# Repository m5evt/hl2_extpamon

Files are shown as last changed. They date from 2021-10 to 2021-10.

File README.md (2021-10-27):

# hl2_extpamon

## Overview

hl2_extpamon

Power amplifier instrumentation board designed to couple to the Hermes-Lite2 SDR. 

The firmware/hardware is designed to couple to an LM35 temperature sensor.

The hardware should cope with upto 8 A of current to a power amplifer. However, at present the current is scaled to a full scale of 5 A. This can be changed in [hl2_extpamon.h](https://github.com/m5evt/hl2_extpamon/blob/main/firmware/hl2_extpamon.h). Other parameters such as automatic temperature turn on for the fan can be configured here.

The module uses an ATTINY414 device with an i2c address of 0x2A. 

## Reading data from device

Data can be read from the device over i2c by send the first data frame as 0x01.

For example, to read temperature and current from the device send:

```
07AA0100
```

This will return a 16 bit number comprised of the following bytes:

| Byte 3  | Byte 2 | Byte 1  | Byte 0 |
| --- | --- |--- | --- |
| Device status | PORTA status |Current | Temperature |

Temperature = e.g. 26 is 26 deg C

Current is scaled to a maximum current of 5 A represented in 255 bits. A return value of 128 = (128 / 255) * 5 = 2.51 A.

PORTA status corresponds to:

| Bit | Description |
|--- | --- |
| 0 | Reserved |
| 1 | HL2 CN8 control |
| 2 | Enable PA power |
| 3 | FAN 1 |
| 4 | FAN 2 |
| 5 | N/a
| 6 | N/a
| 7 | Reserved |

Device status correspod to:

| Bit | Description |
|--- | --- |
| 0 | Sampling ADC5 |
| 1 | Sampling ADC6 |

## Writing data to device

PORTA I/O can be set/clear by writing to address 0x02 in the device. For example, to enable the PA and turn on the fans send:

```
06AA021E
```

## Programming the ATTINY414

To program, the Makefile uses [pymcuprog](https://github.com/microchip-pic-avr-tools/pymcuprog) and UPDI. This does not require any specialist tools other than a TTL USB adapter and a resistor. See [here](https://github.com/mraardvark/pyupdi).

To program the device, from a command line run:
```
make clean && make erase && make program
```

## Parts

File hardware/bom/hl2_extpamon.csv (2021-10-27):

ID | Value |  | Quantiy | Vendor | Order code
C1, C2, C3, C4, C5, C6, C7, C8, C60, C81, C84, C85 | 100n | C_0603_1608Metric_Pad1.08x0.95mm_HandSolder | 12
C83 | 1u | C_0603_1608Metric_Pad1.08x0.95mm_HandSolder | 1
R1, R2 | 10k | R_0603_1608Metric_Pad0.98x0.95mm_HandSolder | 2 | Farnell | 2887144
R4, R5, R6, R7, R8, R16 | 10k | R_0603_1608Metric_Pad0.98x0.95mm_HandSolder | 6
R3, R17 | 1k | R_0603_1608Metric_Pad0.98x0.95mm_HandSolder | 2
R14, R35 | 100 | R_0603_1608Metric_Pad0.98x0.95mm_HandSolder | 2
R31 | 100k | R_0603_1608Metric_Pad0.98x0.95mm_HandSolder | 1
R34 | 0.033 | rsense_1206wide | 1 | Farnell | 3254952
D2, D6 | 1N4148W | D_SOD-123 | 2 | Farnell | 1776392
D1 | BZT52C15-E3-08 | D_SOD-123 | 1 | Farnell | 2420637
U1 | MCP6282E/MS | MSOP-8_3x3mm_P0.65mm | 1 | Farnell | 1852089
U2 | ATtiny414-SS | SOIC-14_3.9x8.7mm_P1.27mm | 1 | Farnell | 2786358
U7 | INA193 | SOT-23-5 | 1 | Farnell | 3005325
FB6 | FB | L_0805_2012Metric | 1 | Farnell | 1800367
Q3, Q6 | IRLML6402 | SOT-23 | 2 | Farnell | 9103503
Q4, Q5 | DTC144E | SOT-23 | 2 | Farnell | 2948628
Q2 | 2N7002 | SOT-23 | 1 | Farnell | 9845313
Q1 | RSJ151P10TL | TO-263-3_TabPin2 | 1 | Farnell | 2706667
J5, J8 | Fan | JST_XH_B2B-XH-A_1x02_P2.50mm_Vertical | 2
J9 | Conn_01x04 | PinHeader_1x05_P2.54mm_Vertical | 1
J7 | Conn_01x08 | PinHeader_1x08_P2.54mm_Vertical | 1
J1, J3, J4 | 12V | TerminalBlock_Phoenix_PT-1,5-2-3.5-H_1x02_P3.50mm_Horizontal | 3 | Farnell | 1841250
J2, J6 | 50VDC | TerminalBlock_Phoenix_PT-1,5-2-5.0-H_1x02_P5.00mm_Horizontal | 2 | Farnell | 1733570
P1, P2, P3, P4 | TST | m3 | 4

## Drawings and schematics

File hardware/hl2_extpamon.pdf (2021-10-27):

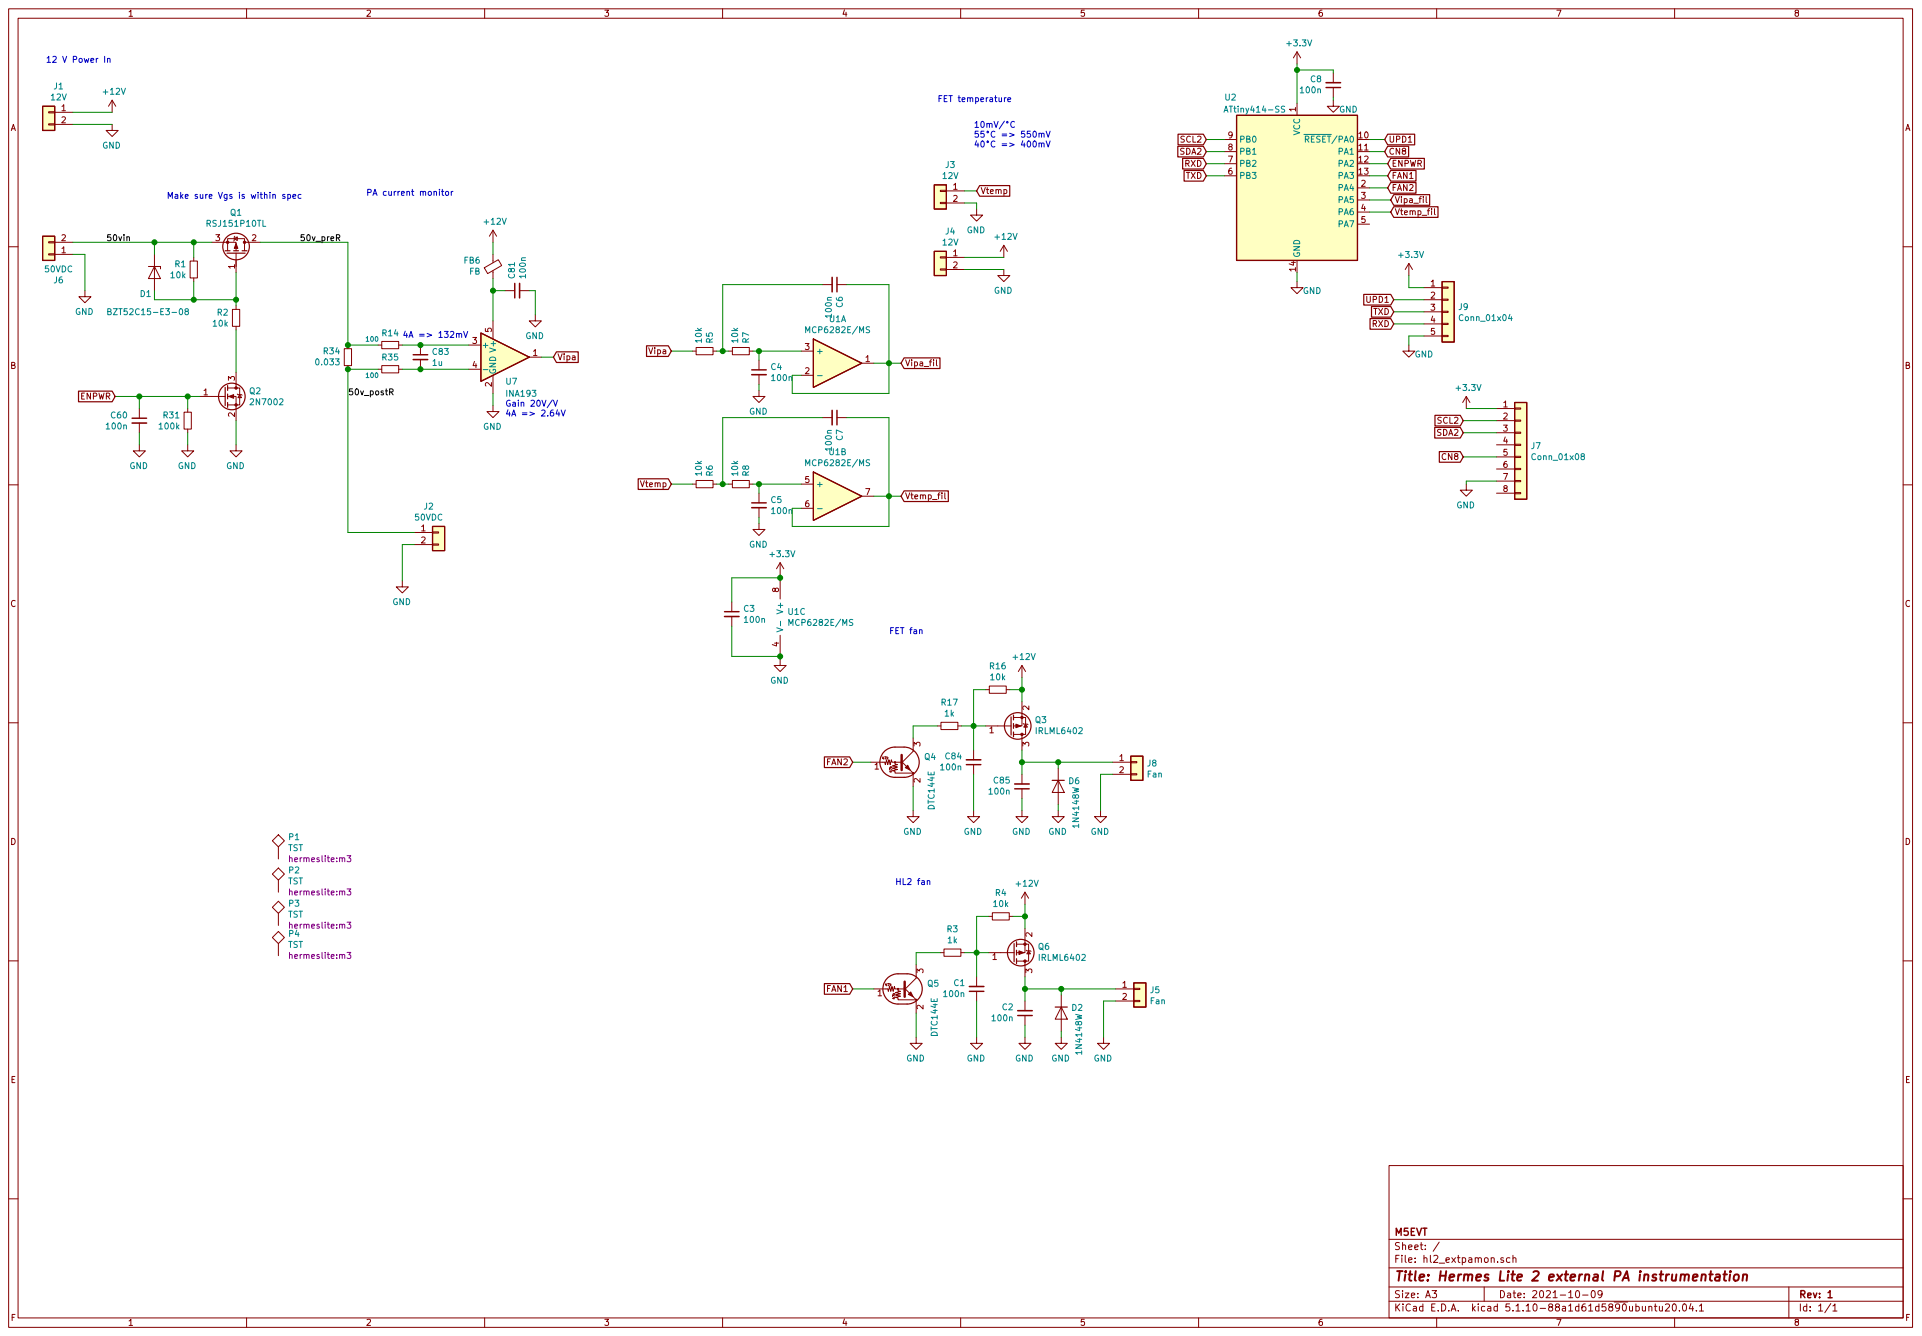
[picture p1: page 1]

FET temperature PA current monitor 4A => 132mV

Make sure Vgs is within spec

File: hl2_extpamon.sch Sheet: / M5EVT GND

Id: 1/1 Title: Hermes Lite 2 external PA instrumentation

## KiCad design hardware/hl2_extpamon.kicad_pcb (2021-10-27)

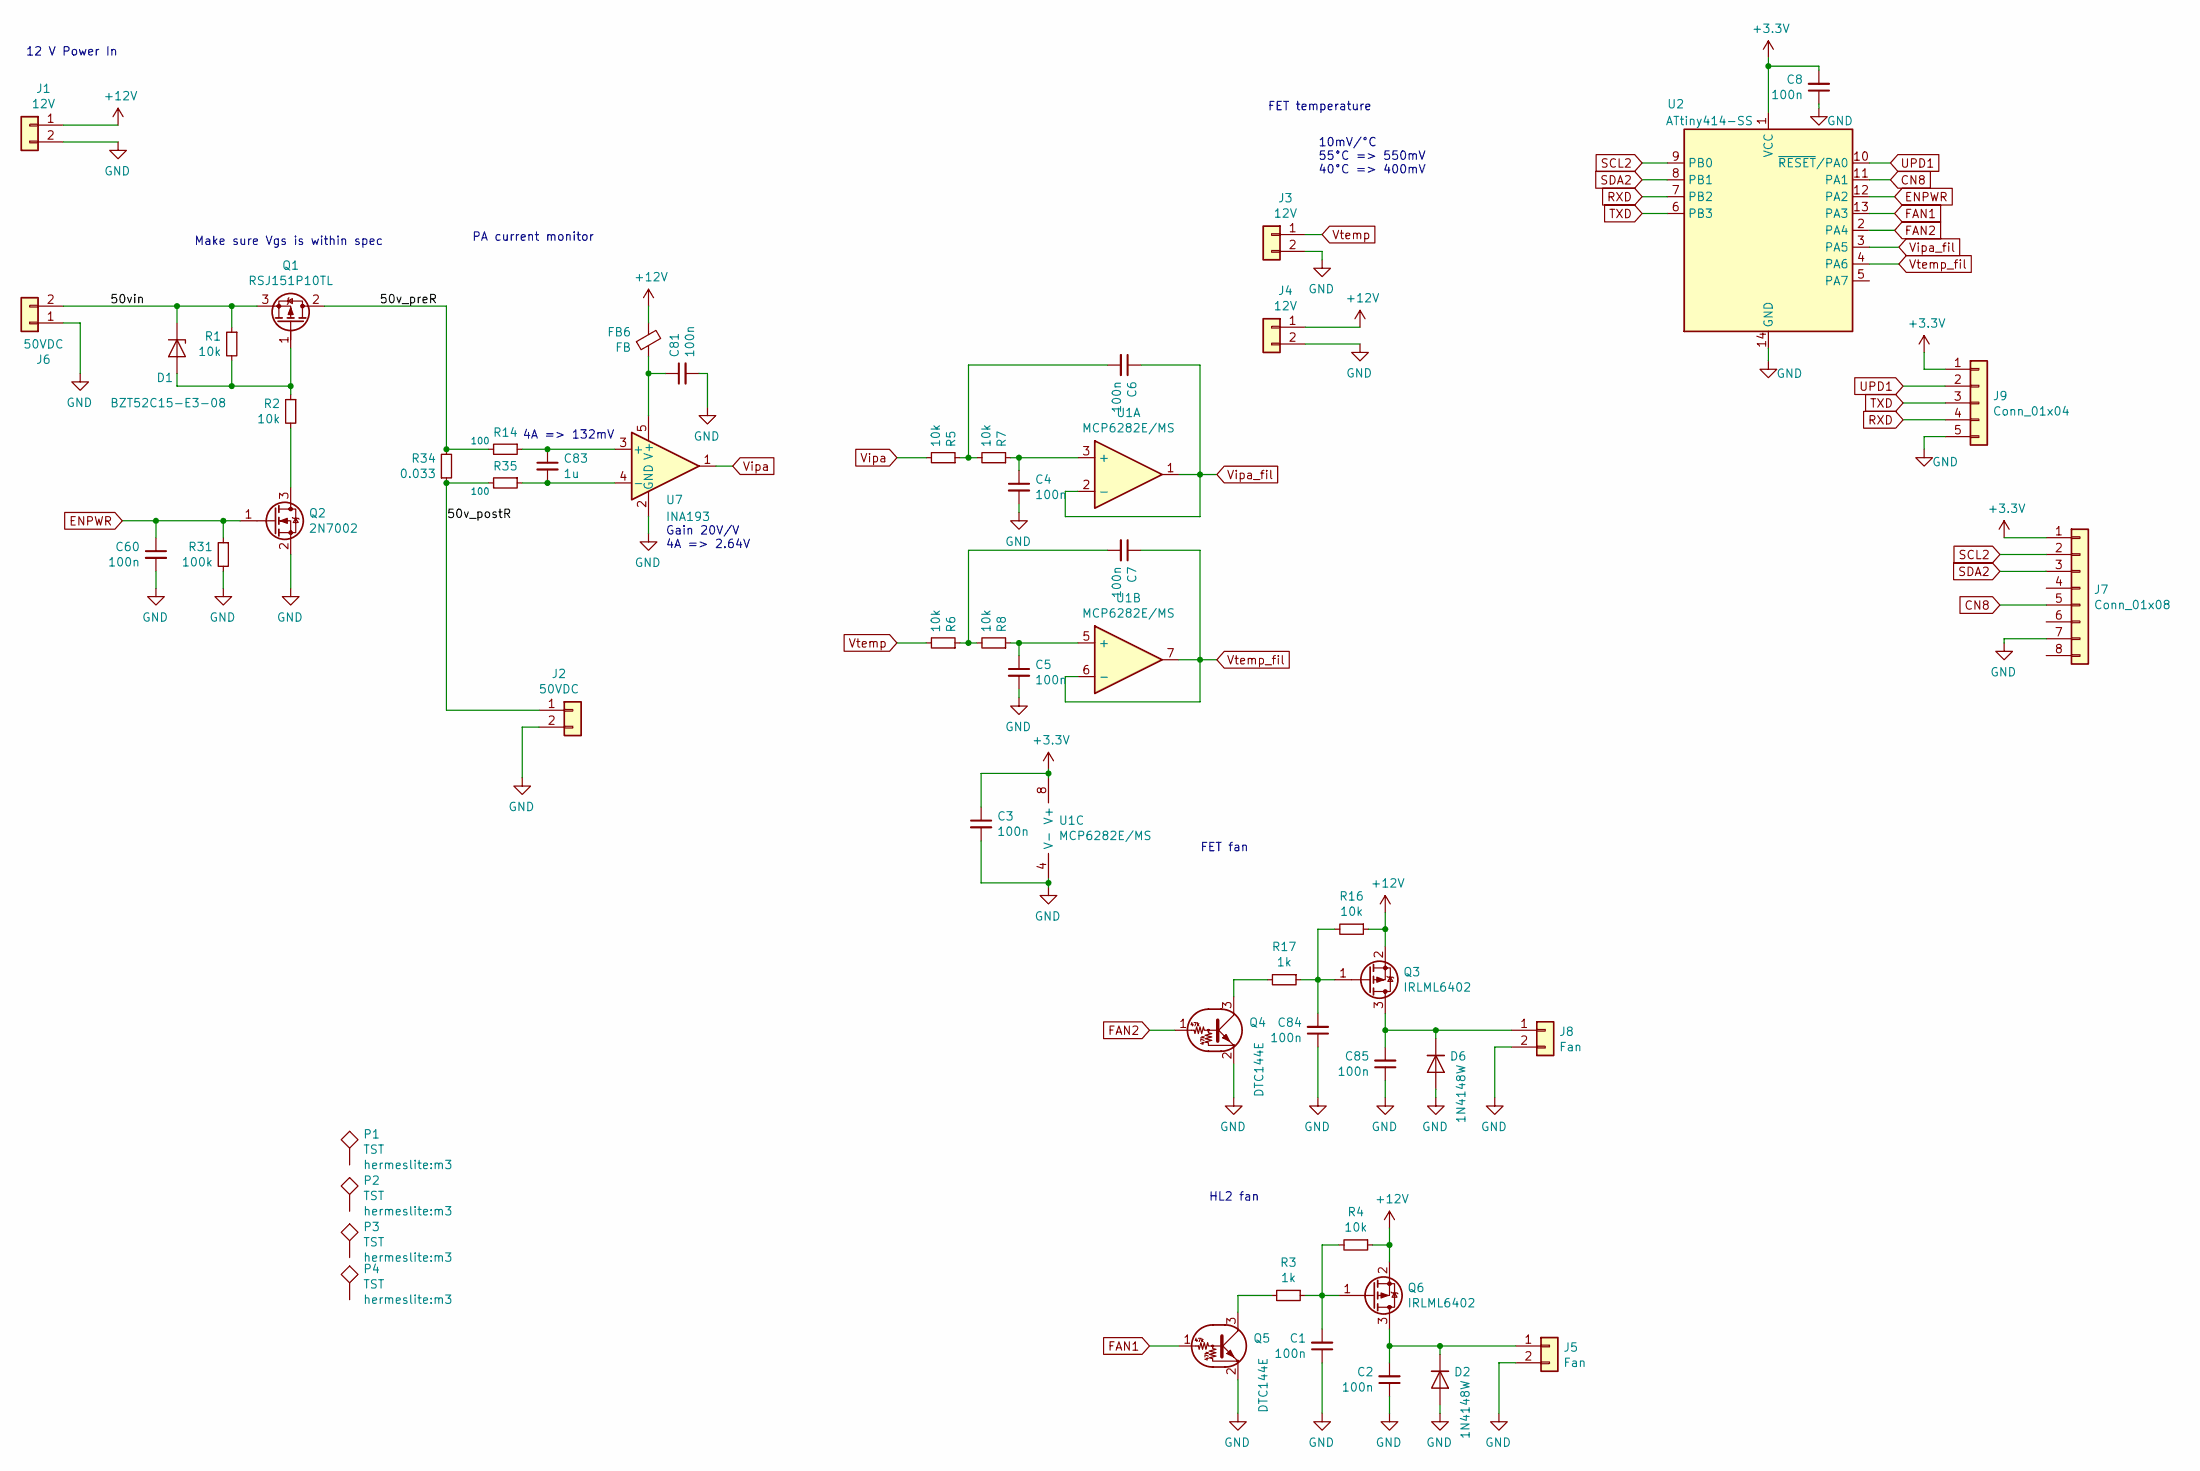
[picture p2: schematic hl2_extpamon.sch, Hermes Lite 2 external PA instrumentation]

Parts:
C1, C2, C3, C4, C5, C6, C7, C8, C60, C81, C84, C85: 100n; C_0603_1608Metric_Pad1.08x0.95mm_HandSolder
C83: 1u; C_0603_1608Metric_Pad1.08x0.95mm_HandSolder
D1: BZT52C15-E3-08; D_SOD-123
D2, D6: 1N4148W; D_SOD-123
FB6: FB; L_0805_2012Metric
J1, J3, J4: 12V; TerminalBlock_Phoenix_PT-1,5-2-3.5-H_1x02_P3.50mm_Horizontal
J2, J6: 50VDC; TerminalBlock_Phoenix_PT-1,5-2-5.0-H_1x02_P5.00mm_Horizontal
J5, J8: Fan; JST_XH_B2B-XH-A_1x02_P2.50mm_Vertical
J7: Conn_01x08; PinHeader_1x08_P2.54mm_Vertical
J9: Conn_01x04; PinHeader_1x05_P2.54mm_Vertical
P1, P2, P3, P4: TST; m3
Q1: RSJ151P10TL; TO-263-3_TabPin2
Q2: 2N7002; SOT-23
Q3, Q6: IRLML6402; SOT-23
Q4, Q5: DTC144E; SOT-23
R1, R2, R4, R5, R6, R7, R8, R16: 10k; R_0603_1608Metric_Pad0.98x0.95mm_HandSolder
R3, R17: 1k; R_0603_1608Metric_Pad0.98x0.95mm_HandSolder
R14, R35: 100; R_0603_1608Metric_Pad0.98x0.95mm_HandSolder
R31: 100k; R_0603_1608Metric_Pad0.98x0.95mm_HandSolder
R34: 0.033; rsense_1206wide
U1: MCP6282E/MS; MSOP-8_3x3mm_P0.65mm
U2: ATtiny414-SS; SOIC-14_3.9x8.7mm_P1.27mm
U7: INA193; SOT-23-5

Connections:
+3V3: C3.1, C8.2, J7.1, J9.1, U1.8 (V+), U2.1 (VCC)
+12V: FB6.2, J1.1, J4.1, Q3.2 (S), Q6.2 (S), R4.1, R16.1
/50v_postR: J2.1, R34.1, R35.2
/50v_preR: Q1.2 (D), R14.2, R34.2
/50vin: D1.1 (K), J6.2, Q1.3 (S), R1.1
CN8: J7.5, U2.11 (PA1)
ENPWR: C60.1, Q2.1 (G), R31.1, U2.12 (PA2)
FAN1: Q5.1 (B), U2.13 (PA3)
FAN2: Q4.1 (B), U2.2 (PA4)
GND: C1.1, C2.1, C3.2, C4.2, C5.2, C8.1, C60.2, C81.2, C84.1, C85.1, D2.2 (A), D6.2 (A), J1.2, J2.2, J3.2, J4.2, J5.2, J6.1, J7.7, J8.2, J9.5, Q2.2 (S), Q4.2 (E), Q5.2 (E), R31.2, U1.4 (V-), U2.14 (GND), U7.2 (GND)
unnamed: C1.2, Q6.1 (G), R3.1, R4.2
unnamed: C2.2, D2.1 (K), J5.1, Q6.3 (D)
unnamed: C4.1, R7.1, U1.3 (+)
unnamed: C5.1, R8.1, U1.5 (+)
unnamed: C6.2, R5.1, R7.2
unnamed: C7.2, R6.1, R8.2
unnamed: C81.1, FB6.1, U7.5 (V+)
unnamed: C83.1, R14.1, U7.3 (+)
unnamed: C83.2, R35.1, U7.4 (-)
unnamed: C84.2, Q3.1 (G), R16.2, R17.1
unnamed: C85.2, D6.1 (K), J8.1, Q3.3 (D)
unnamed: D1.2 (A), Q1.1 (G), R1.2, R2.1
unnamed: Q2.3 (D), R2.2
unnamed: Q4.3 (C), R17.2
unnamed: Q5.3 (C), R3.2
RXD: J9.4, U2.7 (PB2)
SCL2: J7.2, U2.9 (PB0)
SDA2: J7.3, U2.8 (PB1)
TXD: J9.3, U2.6 (PB3)
UPD1: J9.2, U2.10 (~RESET~/PA0)
Vipa: R5.2, U7.1
Vipa_fil: C6.1, U1.1, U1.2 (-), U2.3 (PA5)
Vtemp: J3.1, R6.2
Vtemp_fil: C7.1, U1.6 (-), U1.7, U2.4 (PA6)

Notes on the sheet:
10mV/°C 55°C => 550mV 40°C => 400mV
4A => 132mV
Gain 20V/V 4A => 2.64V
PA current monitor
FET temperature
FET fan
HL2 fan
Make sure Vgs is within spec
12 V Power In

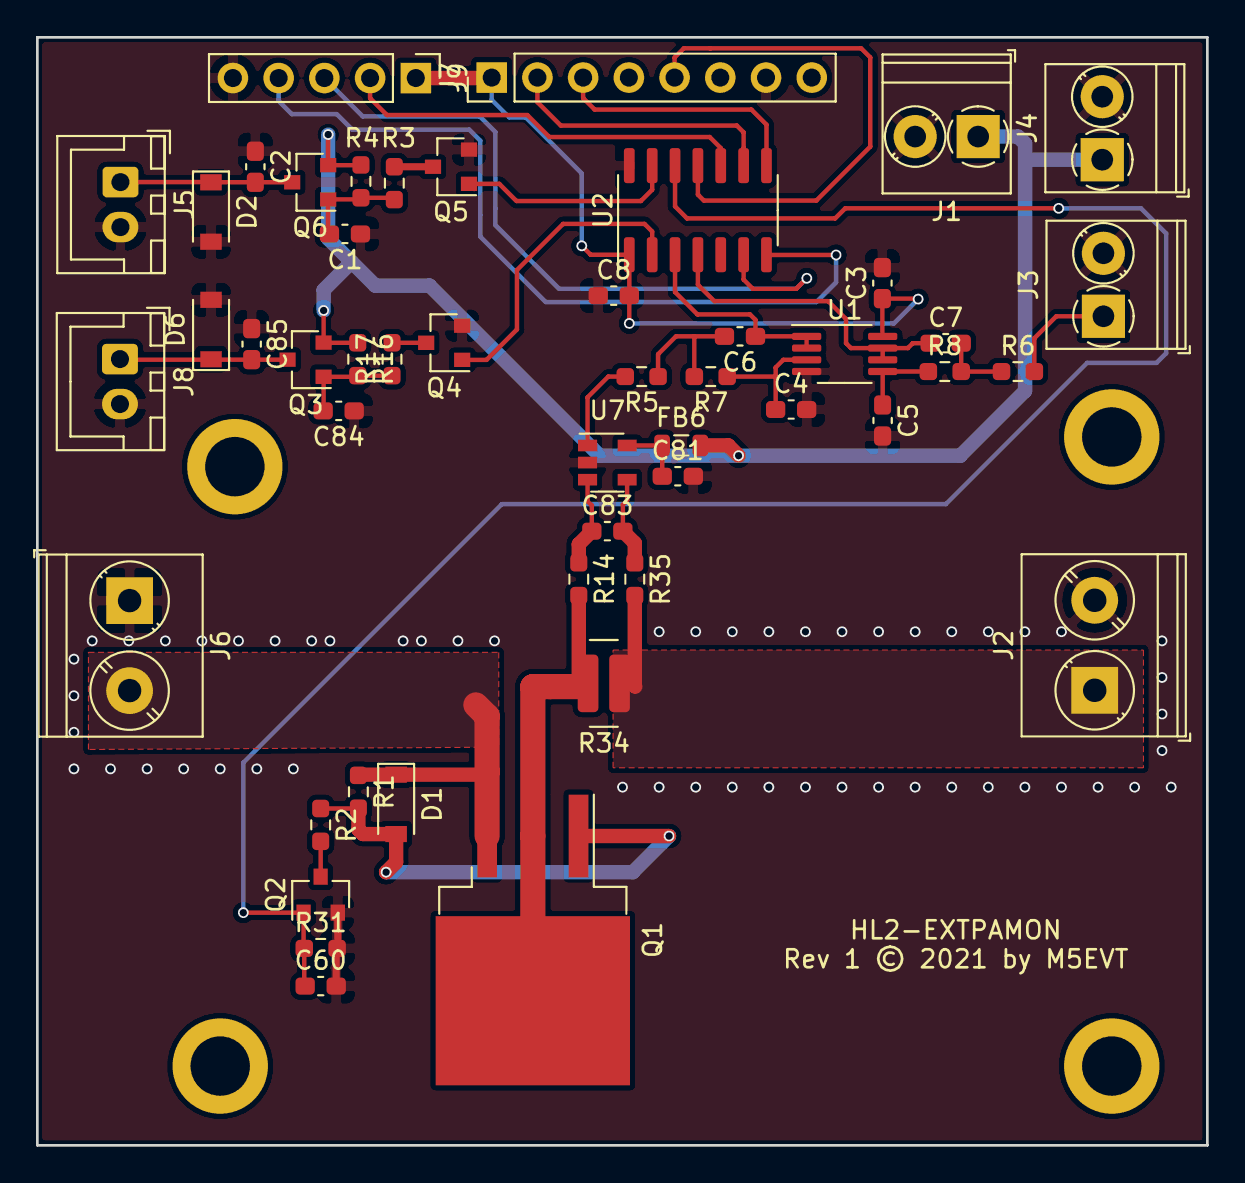
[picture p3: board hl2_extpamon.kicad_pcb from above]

Board: 2 copper layers, 65.0 x 61.6 mm, 53 parts (0 on the bottom side), 34 nets.

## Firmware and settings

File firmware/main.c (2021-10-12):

/*
 *
 * This software is covered by a modified MIT License, see paragraphs 4
 *
 * Copyright (c) 2021 m5evt 
 *
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
 * 4. Parts of this software are adapted from Microchip sample code.
 * Additional license restrictions from Microchip may apply.
 */

#define TEN_MS_PERIOD (0x1388)

#include <avr/io.h>
#include <avr/interrupt.h>

#include "helper.h"
#include "I2CS.h"
#include "hl2_extpamon.h"

// Globals
volatile uint8_t temperature_raw;
volatile uint8_t current_raw;
volatile uint8_t status_reg;
volatile uint8_t fan_counter;
volatile uint8_t trip_current;
volatile uint8_t trip_temperature;


void TCA0_init(void) {
    // enable overflow interrupt 
    TCA0.SINGLE.INTCTRL = TCA_SINGLE_OVF_bm;
    // set Normal mode 
    TCA0.SINGLE.CTRLB = TCA_SINGLE_WGMODE_NORMAL_gc;
    // disable event counting 
    TCA0.SINGLE.EVCTRL &= ~(TCA_SINGLE_CNTEI_bm);
    // set the period 
    TCA0.SINGLE.PER = TEN_MS_PERIOD;
    TCA0.SINGLE.CTRLA = TCA_SINGLE_CLKSEL_DIV16_gc | TCA_SINGLE_ENABLE_bm;
}

void RTC_init(void) {
  //Wait for all register to be synchronized 
  while (RTC.STATUS > 0) {};
  
  RTC.CTRLA = RTC_PRESCALER_DIV1_gc   // 1 
            | 1 << RTC_RTCEN_bp     // Enable: enabled 
            | 0 << RTC_RUNSTDBY_bp; // Run In Standby: disabled
  // Wait for all register to be synchronized 
  while (RTC.PITSTATUS > 0) {} 
  RTC.PITCTRLA = RTC_PERIOD_CYC32_gc  // RTC Clock  Cycles 32 
               | 1 << RTC_PITEN_bp; // Enable: enabled 
 
  RTC.PITINTCTRL = 1 << RTC_PI_bp; //Periodic Interrupt: enabled 
}

void PORT_init(void) {
  // set pin 0 of PORT A as output
  PORTA.DIR |= PIN4_bm;
  PORTA.DIR |= PIN3_bm;
  PORTA.DIR |= PIN1_bm;
  PORTA.DIR |= PIN2_bm;
}

void ADC0_init(void) {
  // Disable digital input buffer
  PORTA.PIN6CTRL &= ~PORT_ISC_gm;
  PORTA.PIN6CTRL |= PORT_ISC_INPUT_DISABLE_gc;
  PORTA.PIN5CTRL &= ~PORT_ISC_gm;
  PORTA.PIN5CTRL |= PORT_ISC_INPUT_DISABLE_gc;

  // Disable pull-up resistor 
  PORTA.PIN6CTRL &= ~PORT_PULLUPEN_bm;
  PORTA.PIN5CTRL &= ~PORT_PULLUPEN_bm;

  ADC0.CTRLC = ADC_PRESC_DIV4_gc
             | ADC_REFSEL_VDDREF_gc;
  ADC0.CTRLA = ADC_ENABLE_bm
             | ADC_RESSEL_10BIT_gc;
}

uint16_t ADC0_read(const uint8_t muxpos) {
  // Select analog input
  ADC0.MUXPOS = (muxpos<<0); 
   //Start conversion
  ADC0.COMMAND = ADC_STCONV_bm;
  // Wait til done
  while (!(ADC0.INTFLAGS & ADC_RESRDY_bm)) {;}
  //Done, clear INT
  ADC0.INTFLAGS = ADC_RESRDY_bm;
  // 12 bit result
  return ADC0.RES;
}

// Send data to the HL2
uint8_t i2cGetData(const uint8_t read_addr, const uint8_t this_byte){
  switch (read_addr) {
    case FLAGS_STATUS:
      return IOPORT;
      break;
    case MRF101_STATUS:
      switch (this_byte) {
        case 0:
          return temperature_raw;
        case 1:
          return current_raw;
        case 2:
          return IOPORT;
        case 3:
          return status_reg;
        default: break;
      break;
    }
  }
  return 0x1f;
}

// Read byte sent from HL2
uint8_t i2cWriteData(const uint8_t write_addr, const uint8_t data) {
  switch (write_addr) {
    case SET_CFG:
      IOPORT = data;
      break;
    case SET_CURRENT_TRIP:
      trip_current = data;
      break;
    case SET_TEMP_TRIP:
      trip_temperature = data;
      break;
    default: break;
  }
  return IOPORT;
}

void SetupProtectedWrites(void) {
    _PROTECTED_WRITE(CLKCTRL.MCLKCTRLB, CLKCTRL_PDIV_2X_gc | CLKCTRL_PEN_bm);
    _PROTECTED_WRITE(CLKCTRL.MCLKCTRLA, !CLKCTRL_CLKOUT_bm | CLKCTRL_CLKSEL_OSC20M_gc);
    _PROTECTED_WRITE(CLKCTRL.OSC32KCTRLA, CLKCTRL_RUNSTDBY_bp);
}

void InitUc(void) {
    SetupProtectedWrites();
    PORT_init();
    TCA0_init();
    RTC_init();
    ADC0_init();
    I2CS_init();
}

void InitStatusFlags(void) {
    // Fans off, ADC mux 0, CN8 disabled, PWR disabled 
    IOPORT = 0x00;
}

void GetTemperature(void) {
  uint16_t temp_raw = ADC0_read(TEMPERATURE);
  float this_temperature = ((float)temp_raw * (3.3 / 1024)) * 100;
            
  //temperature_raw = (uint8_t)(((float)temp_raw * (3.3 / 1024)) * 100);
  temperature_raw = (uint8_t)this_temperature;
  // Every 4080 ms sample the temperature to decide
  // if; fan turns on, fan stays off, fan turns off (after being on)
  if (fan_counter == 0) {
    if (temperature_raw > FAN_TEMP_THRESHOLD) {
      FAN1 = 1;
    }
    else {
      FAN1 = 0;
    }
    fan_counter++;
  } 
  else if (fan_counter == 255) {
    fan_counter = 0;
  }
  else if (fan_counter > 0) {
    fan_counter++;
  }
  if (temperature_raw > trip_temperature) {
    ENPWR = 0;
  }
  CBI(status_reg, 0);      
}

void GetCurrent(void) {
  uint16_t temp = ADC0_read(CURRENT);
  // Convert ADC bits to real value e.g. 4.00 A 
  float this_c = ((float)temp * (3.3 /1024) / 20) / CURRENT_SENSE_R;
  // To fit into an 8 bit reg, measured value to full scale
  current_raw = (uint8_t)((this_c / CURRENT_FULL_SCALE) * 255);
  if (current_raw > trip_current) {
    ENPWR = 0;
  }
  SBI(status_reg, 0);      
}

int main(void) {
    // Setup micro specifics 
    InitUc();
    // I2C callbacks to application code
    I2c_set_callbacks(i2cGetData, i2cWriteData);
    // Setup application code
    InitStatusFlags();
   
    // Init globals
    temperature_raw = 0;
    current_raw = 0;
    status_reg = 0;
    fan_counter = 0;
    trip_current = 178;
    trip_temperature = 45;

    // enable global interrupts */
    sei();
    
    temperature_raw = ADC0_read(TEMPERATURE);

    for (;;) {
       if ((status_reg & DO_ADC_M) == DO_ADC_M) {
     //PORTA.OUTTGL = PIN1_bm;
         if ((status_reg & ADCSAMPLE_M) == ADCSAMPLE_M) {
           GetTemperature();
         } 
         else {
           PORTA.OUTSET = PIN1_bm;
           GetCurrent();
           PORTA.OUTCLR = PIN1_bm;
         }
         CBI(status_reg, 1);
       }
    }
}

// ADC sampling timer (8 ms tick)
ISR(TCA0_OVF_vect) {
    // Set ADC sample flag
    SBI(status_reg, 1);
    // Clear flag 
    TCA0.SINGLE.INTFLAGS = TCA_SINGLE_OVF_bm;
}

// 1 ms tick 
ISR(RTC_PIT_vect) {					
    I2c_timeout_counter_inc();
    // Clear flag
  	RTC.PITINTFLAGS = RTC_PI_bm;		
}

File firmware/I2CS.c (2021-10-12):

/*
 * I2CS.c
 *
 * I2C client
 * 
 * This software is covered by a modified MIT License, see paragraphs 4 and 5
 *
 * Copyright (c) 2019 Dieter Reinhardt
 * Copyright (c) 2021 m5evt
 *
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
 * 4. This software is strictly NOT intended for safety-critical or life-critical applications.
 * If the user intends to use this software or parts thereof for such purpose additional
 * certification is required.
 *
 * 5. Parts of this software are adapted from Microchip I2C client driver sample code.
 * Additional license restrictions from Microchip may apply.
 */
#include <avr/io.h>
#include <avr/interrupt.h>
#include <stdbool.h>
#include <util/delay.h>
#include "I2CS.h"
#include "port.h"

static volatile uint8_t	read_addr;				// address received from controller
volatile uint8_t  timeout_cnt;				// 1ms timeout tick counter
volatile uint8_t	num_bytes = 0;		// number of bytes sent/received in transaction

// Timer for read operations 
void I2c_timeout_counter_inc(void) {
  timeout_cnt++;
}

// Initialize I2C interface
void I2CS_init(void) {
	PORTB_set_pin_dir(0, PORT_DIR_OUT);							// SCL = PB0
	PORTB_set_pin_level(0, false);
	PORTB_set_pin_pull_mode(0, PORT_PULL_OFF);
	PORTB_pin_set_inverted(0, false);
	PORTB_pin_set_isc(0, PORT_ISC_INTDISABLE_gc);
	PORTB_set_pin_dir(1, PORT_DIR_OUT);							// SDA = PB1
	PORTB_set_pin_level(1, false);
	PORTB_set_pin_pull_mode(1, PORT_PULL_OFF);
	PORTB_pin_set_inverted(1, false);
	PORTB_pin_set_isc(1, PORT_ISC_INTDISABLE_gc);

	TWI0.CTRLA = 1 << TWI_FMPEN_bp								// FM Plus Enable: disabled
	             | TWI_SDAHOLD_50NS_gc					  // Typical 50ns hold time
	             | TWI_SDASETUP_8CYC_gc;				  // SDA setup time is 8 clock cycles

	TWI0.SADDR = CLIENT_ADDRESS << TWI_ADDRMASK_gp  // client Address (8 bit address, i. e. bit 0 = 0, will be substituted by R/W bit)
	             | 0 << TWI_ADDREN_bp;							// General Call Recognition Enable: disabled

	TWI0.SCTRLA = 1 << TWI_APIEN_bp								// Address/Stop Interrupt Enable: enabled
	              | 1 << TWI_DIEN_bp							// Data Interrupt Enable: enabled
	              | 1 << TWI_ENABLE_bp						// Enable TWI client: enabled
	              | 1 << TWI_PIEN_bp							// Stop Interrupt Enable: enabled
	              | 0 << TWI_PMEN_bp							// Promiscuous Mode Enable: disabled
	              | 0 << TWI_SMEN_bp;							// Smart Mode Enable: disabled
  read_addr = 0;
  timeout_cnt = 0;
}

static uint8_t (*i2c_read_callback)(uint8_t, uint8_t);
static uint8_t (*i2c_write_callback)(uint8_t, uint8_t);

void I2c_set_callbacks(uint8_t (*read)(uint8_t, uint8_t),
                       uint8_t (*write)(uint8_t, uint8_t)) {
  i2c_read_callback = read;
  i2c_write_callback = write;
}

// send ACK
void I2c_ack(void) {
  TWI0.SCTRLB = TWI_ACKACT_ACK_gc | TWI_SCMD_RESPONSE_gc;	 
}

// send NACK	
void I2c_nack(void) {
  TWI0.SCTRLB = TWI_ACKACT_NACK_gc | TWI_SCMD_RESPONSE_gc; 
}

// error handler, should reset I2C client internal state	
static void I2C_error_handler(void) {
	TWI0.SSTATUS |= (TWI_APIF_bm | TWI_DIF_bm);					// clear interrupt flags

	PORTB_set_pin_dir(0, PORT_DIR_IN);							// SCL = PB0
	PORTB_set_pin_dir(1, PORT_DIR_IN);							// SDA = PB1
	TWI0.SCTRLA = 0;											// disable client
	_delay_us(10);												// SCL, SDA tristated high
	PORTB_set_pin_dir(0, PORT_DIR_OUT);							// SCL = PB0
	PORTB_set_pin_dir(1, PORT_DIR_OUT);							// SDA = PB1
	// re-enable client
	TWI0.SCTRLA = 1 << TWI_APIEN_bp								// Address/Stop Interrupt Enable: enabled
				| 1 << TWI_DIEN_bp								// Data Interrupt Enable: enabled
				| 1 << TWI_ENABLE_bp							// Enable TWI client: enabled
				| 1 << TWI_PIEN_bp								// Stop Interrupt Enable: enabled
				| 0 << TWI_PMEN_bp								// Promiscuous Mode Enable: disabled
				| 0 << TWI_SMEN_bp;								// Smart Mode Enable: disabled
  I2c_nack();
}

void I2cRead(void) {
  timeout_cnt = 0;									
  // wait until Clock Hold flag set
  while (!(TWI0.SSTATUS & TWI_CLKHOLD_bm)) {
    if (timeout_cnt > 2) return;					
  }
  if (i2c_read_callback) TWI0.SDATA = i2c_read_callback(read_addr, num_bytes);
	num_bytes++;									
}

void I2cWrite(void) {
  // controller wishes to write to client
	if (num_bytes == 0) read_addr = TWI0.SDATA;
  if (num_bytes > 0) {
	   uint8_t data = TWI0.SDATA;
	  if (i2c_write_callback) TWI0.SDATA = i2c_write_callback(read_addr, data);
  }
  num_bytes++;									
  if (num_bytes > MAX_TRANSACTION) {		
    I2c_nack();
  }	
  else {
    I2c_ack();
  }			
}

// I2C IRQ handler
// WARNING - do NOT clear interrupt flags during transaction, this will lead to false data when controller reads
ISR(TWI0_TWIS_vect) {
  // APIF && DIF, invalid state 
	if ((TWI0.SSTATUS & TWI_APIF_bm) && (TWI0.SSTATUS & TWI_DIF_bm)) { 
		I2C_error_handler();								 
		return;
	}
  // Collision - client has not been able to transmit a high data or NACK bit
	if (TWI0.SSTATUS & TWI_COLL_bm) {							
		I2C_error_handler();	
		return;
	}
  // Bus Error - illegal bus condition
	if (TWI0.SSTATUS & TWI_BUSERR_bm) {							
		I2C_error_handler();				
		return;
	}

  // APIF && AP - valid address has been received
	if ((TWI0.SSTATUS & TWI_APIF_bm) && (TWI0.SSTATUS & TWI_AP_bm)) { 
    num_bytes = 0;									
    I2c_ack();
	  // controller wishes to read from client (else return and wait for data from controller)
    if (TWI0.SSTATUS & TWI_DIR_bm) {							
      I2cRead();
      I2c_ack();
	 	}
		return;
	}
  // DIF - Data Interrupt Flag - client byte transmit or receive completed
	if (TWI0.SSTATUS & TWI_DIF_bm) {							
    // controller wishes to read from client
		if (TWI0.SSTATUS & TWI_DIR_bm) {						
			if (!(TWI0.SSTATUS & TWI_RXACK_bm)) {				
        I2cRead();
        I2c_ack();
			} 
      else {										
        // Received NACK from controller 
        // Reset module
				TWI0.SSTATUS |= (TWI_DIF_bm | TWI_APIF_bm);		
				TWI0.SCTRLB = TWI_SCMD_COMPTRANS_gc;				
			}
		} 
    else {												
      I2cWrite();
		}
		return;
	}
	// APIF && !AP - Stop has been received
	if ((TWI0.SSTATUS & TWI_APIF_bm) && (!(TWI0.SSTATUS & TWI_AP_bm))) { 
		TWI0.SCTRLB = TWI_SCMD_COMPTRANS_gc;
		return;
	}
}

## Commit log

2021-10-10 Properly fix read/write i2c
    [I2CS.c, main.c]
2021-10-10 change current and temp scaling
2021-10-12 Fix current sampling
2021-10-27 Upload schematic, PCB and BoM
    [hl2_extpamon-B_Cu.gbr, hl2_extpamon-B_Mask.gbr, hl2_extpamon-B_Paste.gbr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]

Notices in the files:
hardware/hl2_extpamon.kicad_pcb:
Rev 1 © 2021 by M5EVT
